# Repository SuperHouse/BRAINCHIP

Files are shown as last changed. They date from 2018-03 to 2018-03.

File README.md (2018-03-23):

Building Brain Home Automation Controller (CHIP version)
=========================================================
Copyright 2017 SuperHouse Automation Pty Ltd  www.superhouse.tv  

Home automation controller based on a C.H.I.P. The CHIP
attaches to this board, which is Arduino-compatible (ATmega328P) and
includes 433MHz transmitter and receiver modules connected to the
Arduino. The Arduino can communicate with the CHIP via serial, and
can send / receive RF messages using the 433MHz modules.

Features:

 * ATmega328P MCU
 * 433MHz transmitter
 * 433MHz receiver
 * Status LEDs

INSTALLATION
------------
The design is saved as an EAGLE project. EAGLE PCB design software is
available from www.cadsoftusa.com free for non-commercial use. To use
this project download it and place the directory containing these files
into the "eagle" directory on your computer. Then open EAGLE and
navigate to the project.

CREDITS
-------
Designed by Jonathan Oxer jon@oxer.com.au

DISTRIBUTION
------------
The specific terms of distribution of this project are governed by the
license referenced below.

LICENSE
-------
Licensed under the TAPR Open Hardware License (www.tapr.org/OHL).
The "license" folder within this repository also contains a copy of
this license in plain text format.

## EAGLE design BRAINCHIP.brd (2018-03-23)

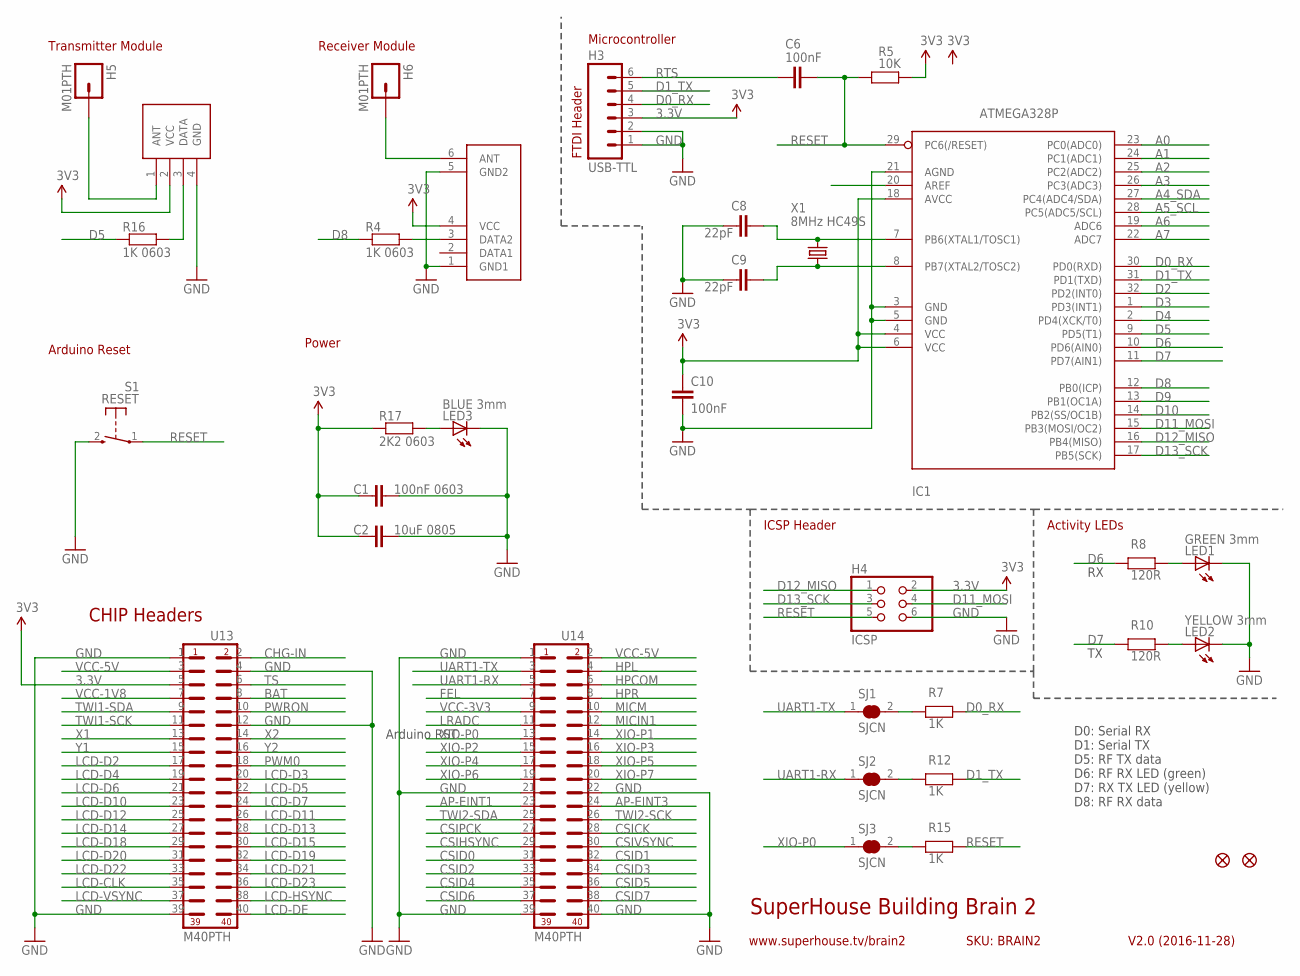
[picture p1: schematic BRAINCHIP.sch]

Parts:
C1: 100nF 0603; 0603
C2: 10uF 0805; C0805
C6, C10: 100nF; 0603
C8, C9: 22pF; 0603
H3: USB-TTL; 1X06
H4: ICSP; 2X03
H5, H6: M01PTH; 1X01
IC1: ATMEGA328P; TQFP32-08
IC3: RXB1; RX-B1-SHORT-FLAT
IC4: TX-C1FLAT; TX-C1-FLAT
LED1: GREEN 3mm; LED3MM
LED2: YELLOW 3mm; LED3MM
LED3: BLUE 3mm; LED3MM
R4, R16: 1K 0603; 0603
R5: 10K; 0603
R7, R12, R15: 1K; 0603
R8, R10: 120R; 0603
R17: 2K2 0603; 0603
S1: RESET; TACTILE_SWITCH_SMD_2PIN_TINY
SJ1, SJ2, SJ3: SJCN; SJC
U13, U14: M40PTH; 2X20
U$5, U$6: FIDUCIAL1X2.5; FIDUCIAL-1X2.5
X1: 8MHz HC49S; HC49U-V

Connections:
3.3V: C1.1, C2.2, C10.1, H3.3, H4.2, IC1.4 (VCC), IC1.6 (VCC), IC1.18 (AVCC), IC3.4 (VCC), IC4.2 (VCC), R5.2, R17.1, U13.5
A0: IC1.23 (PC0(ADC0))
A1: IC1.24 (PC1(ADC1))
A2: IC1.25 (PC2(ADC2))
A3: IC1.26 (PC3(ADC3))
A4_SDA: IC1.27 (PC4(ADC4/SDA))
A5_SCL: IC1.28 (PC5(ADC5/SCL))
A6: IC1.19 (ADC6)
A7: IC1.22 (ADC7)
AP-EINT1: U14.23
AP-EINT3: U14.24
AREF: IC1.20 (AREF)
BAT: U13.8
CHG-IN: U13.2
CSICK: U14.28
CSID0: U14.31
CSID1: U14.32
CSID2: U14.33
CSID3: U14.34
CSID4: U14.35
CSID5: U14.36
CSID6: U14.37
CSID7: U14.38
CSIHSYNC: U14.29
CSIPCK: U14.27
CSIVSYNC: U14.30
D0_RX: H3.4, IC1.30 (PD0(RXD)), R7.1
D1_TX: H3.5, IC1.31 (PD1(TXD)), R12.1
D2: IC1.32 (PD2(INT0))
D3: IC1.1 (PD3(INT1))
D4: IC1.2 (PD4(XCK/T0))
D5: IC1.9 (PD5(T1)), R16.1
D6: IC1.10 (PD6(AIN0)), R8.2
D7: IC1.11 (PD7(AIN1)), R10.2
D8: IC1.12 (PB0(ICP)), R4.1
D9: IC1.13 (PB1(OC1A))
D10: IC1.14 (PB2(SS/OC1B))
D11_MOSI: H4.4, IC1.15 (PB3(MOSI/OC2))
D12_MISO: H4.1, IC1.16 (PB4(MISO))
D13_SCK: H4.3, IC1.17 (PB5(SCK))
FEL: U14.7
GND: C1.2, C2.1, C8.1, C9.1, C10.2, H3.1, H3.2, H4.6, IC1.3 (GND), IC1.5 (GND), IC1.21 (AGND), IC3.1 (GND1), IC3.5 (GND2), IC4.4 (GND), LED1.K (C), LED2.K (C), LED3.K (C), S1.2 (S), U13.1, U13.4, U13.12, U13.39, U14.1, U14.21, U14.22, U14.39, U14.40
HPCOM: U14.6
HPL: U14.4
HPR: U14.8
LCD-CLK: U13.35
LCD-D2: U13.17
LCD-D3: U13.20
LCD-D4: U13.19
LCD-D5: U13.22
LCD-D6: U13.21
LCD-D7: U13.24
LCD-D10: U13.23
LCD-D11: U13.26
LCD-D12: U13.25
LCD-D13: U13.28
LCD-D14: U13.27
LCD-D15: U13.30
LCD-D18: U13.29
LCD-D19: U13.32
LCD-D20: U13.31
LCD-D21: U13.34
LCD-D22: U13.33
LCD-D23: U13.36
LCD-DE: U13.40
LCD-HSYNC: U13.38
LCD-VSYNC: U13.37
LRADC: U14.11
MICIN1: U14.12
MICM: U14.10
unnamed: IC3.3 (DATA2), R4.2
unnamed: LED3.A, R17.2
unnamed: H6.1, IC3.6 (ANT)
unnamed: H5.1, IC4.1 (ANT)
unnamed: IC4.3 (DATA), R16.2
unnamed: C8.2, IC1.7 (PB6(XTAL1/TOSC1)), X1.2
unnamed: C9.2, IC1.8 (PB7(XTAL2/TOSC2)), X1.1
unnamed: LED1.A, R8.1
unnamed: LED2.A, R10.1
unnamed: R7.2, SJ1.2
unnamed: R12.2, SJ2.2
unnamed: R15.2, SJ3.2
PWM0: U13.18
PWRON: U13.10
RESET: C6.2, H4.5, IC1.29 (PC6(/RESET)), R5.1, R15.1, S1.1
RTS: C6.1, H3.6
TS: U13.6
TWI1-SCK: U13.11
TWI1-SDA: U13.9
TWI2-SCK: U14.26
TWI2-SDA: U14.25
UART1-RX: SJ2.1, U14.5
UART1-TX: SJ1.1, U14.3
VCC-1V8: U13.7
VCC-3V3: U14.9
VCC-5V: U13.3, U14.2
X1: U13.13
X2: U13.14
XIO-P0: SJ3.1, U14.13
XIO-P1: U14.14
XIO-P2: U14.15
XIO-P3: U14.16
XIO-P4: U14.17
XIO-P5: U14.18
XIO-P6: U14.19
XIO-P7: U14.20
Y1: U13.15
Y2: U13.16

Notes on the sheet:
CHIP Headers
Power
Receiver Module
D0: Serial RX D1: Serial TX D5: RF TX data D6: RF RX LED (green) D7: RX TX LED (yellow) D8: RF RX data
ICSP Header
Microcontroller
FTDI Header
Transmitter Module
Arduino Reset
Activity LEDs
Arduino RST
SuperHouse Building Brain 2
V2.0 (2016-11-28)
www.superhouse.tv/brain2
SKU: BRAIN2

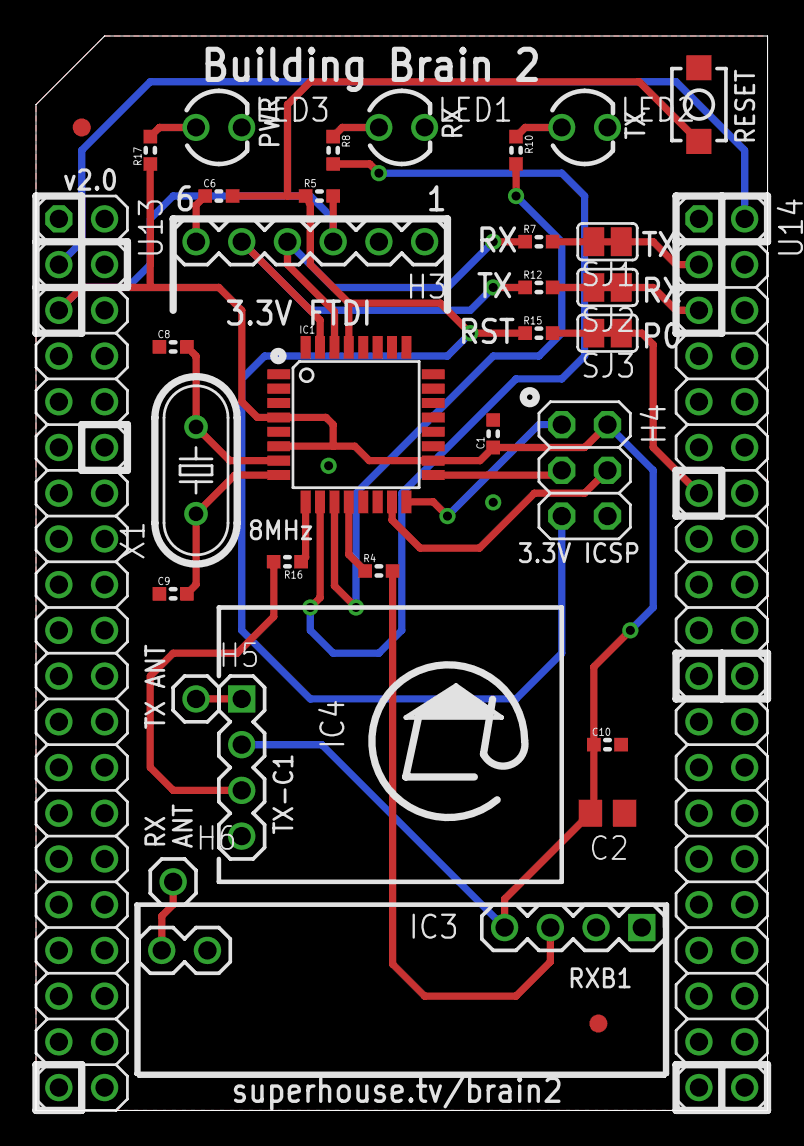
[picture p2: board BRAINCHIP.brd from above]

Board: 2 copper layers, 40.6 x 59.7 mm, 34 parts (0 on the bottom side), 29 nets.

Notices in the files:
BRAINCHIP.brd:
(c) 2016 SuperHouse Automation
